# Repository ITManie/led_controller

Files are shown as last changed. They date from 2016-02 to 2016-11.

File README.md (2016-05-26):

# led-controller





Arduino project to control RGB LED strip

## Part list
 - IQRF Development set [IQRF DS-START-04](http://eshop.iqrf.org/products/detail/DS-START-04)
 - IQRF Breakout board [IQRF BB-01](http://eshop.iqrf.org/products/detail/IQRF-BB-01)
 - IQRF gateway (for example [IQRF GW-ETH-02A](http://eshop.iqrf.org/products/detail/GW-ETH-02A%2872D%29))
 - Atmel MCU with Arduino firmware or Adruino (for example [Arduino Nano](http://www.tme.eu/en/details/a000005/arduino-development-kits/arduino/arduino-nano/))
 - 3x [STMicroelectronics TIP122](http://www.tme.eu/en/details/tip122/npn-tht-darlington-transistors/st-microelectronics/)
 - 5V voltage stabiliser (for example [ON Semiconductor MC78M05CTG](http://www.tme.eu/en/details/mc78m05ctg/unregulated-voltage-regulators/on-semiconductor/))
 - RGB LED strip (for example [OptoFlash OPRGB5060-6012B](http://www.tme.eu/en/details/oprgb5060-6012b/light-sources-led-ribbon/optoflash/))
 - 5,5/2,1mm DC jack (for example [CLIFF FC68148](http://www.tme.eu/en/details/fc68148/dc-power-connectors/cliff/))
 - 12V power supply (for example [ESPE ZSIDT12/3A](http://www.tme.eu/en/details/zsidt12_3a/mains-power-supplies/espe/))
 - terminal block PCB mount (for example [Degson Electronics DG300-5.0-02P-12-00A(H)](http://www.tme.eu/en/details/dg300-5.0-2p12/terminal-blocks-pcb-mount/degson-electronics/dg300-50-02p-12-00ah/))

## Arduino libraries

 * [IQRF](https://github.com/iqrfsdk/clibiqrf-arduino)
 * [MsTimer2](https://github.com/PaulStoffregen/MsTimer2)

## Packets

### Ping
<table>
<tr>
<th>0-FF</th>
<th>100-1FF</th>
<th>200-2FF</th>
<th>300-3FF</th>
<th>400-4FF</th>
<th>500-5FF</th>
</tr>
<tr>
<td>version</td>
<td>type</td>
<td colspan="4">address</td>
</tr>
<tr>
<td>0</td>
<td>0</td>
<td>0-FF</td>
<td>0-FF</td>
<td>0-FF</td>
<td>0-FF</td>
</tr>
</table>

### Pong
<table>
<tr>
<th>0-FF</th>
<th>100-1FF</th>
<th>200-2FF</th>
<th>300-3FF</th>
<th>400-4FF</th>
<th>500-5FF</th>
</tr>
<tr>
<td>version</td>
<td>type</td>
<td colspan="4">address</td>
</tr>
<tr>
<td>0</td>
<td>1</td>
<td>0-FF</td>
<td>0-FF</td>
<td>0-FF</td>
<td>0-FF</td>
</tr>
</table>

### Set color
<table>
<tr>
<th>00-FF</th>
<th>100-1FF</th>
<th>200-2FF</th>
<th>300-3FF</th>
<th>400-4FF</th>
<th>500-5FF</th>
<th>600-6FF</th>
<th>700-7FF</th>
<th>800-8FF</th>
<th>900-9FF</th>
</tr>
<tr>
<td>version</td>
<td>type</td>
<td colspan="4">address</td>
<td>red</td>
<td>green</td>
<td>blue</td>
<td>alpha</td>
</tr>
<tr>
<td>0</td>
<td>2</td>
<td>0-FF</td>
<td>0-FF</td>
<td>0-FF</td>
<td>0-FF</td>
<td>0-FF</td>
<td>0-FF</td>
<td>0-FF</td>
<td>0-1</td>
</tr>
</table>

## Schema
### Prototype
Schema
### Production
Schema

## License
led-controller is licensed under the GPLv3 license:

 > Copyright (C) 2016 Roman Ondráček
 > 
 > This program is free software: you can redistribute it and/or modify
 > it under the terms of the GNU General Public License as published by
 > the Free Software Foundation, either version 3 of the License, or
 > (at your option) any later version.
 > 
 > This program is distributed in the hope that it will be useful,
 > but WITHOUT ANY WARRANTY; without even the implied warranty of
 > MERCHANTABILITY or FITNESS FOR A PARTICULAR PURPOSE.  See the
 > GNU General Public License for more details.
 > 
 > You should have received a copy of the GNU General Public License
 > along with this program.  If not, see <http://www.gnu.org/licenses/>.

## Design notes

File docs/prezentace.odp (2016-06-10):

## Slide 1

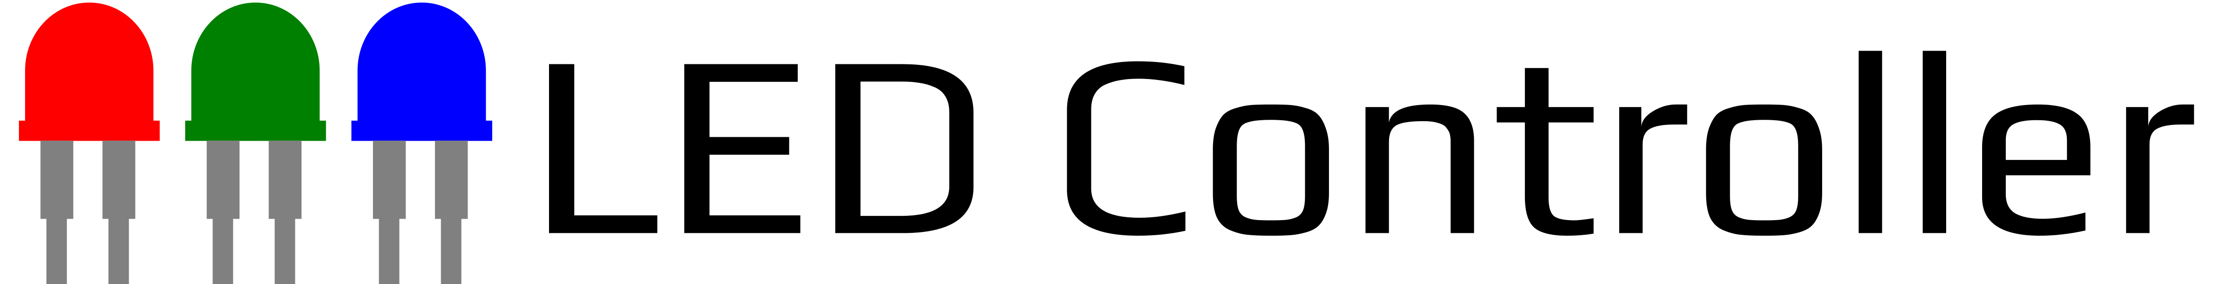
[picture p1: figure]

## Seznámení s projektem

LED Controller je open source (https://gitlab.com/Roman3349/led-controller) projekt, který ovládá RGB LED pásek. Používá IQRF bezdrátové moduly, IQRF Cloud, IQRF Ethernet bránu a Atmel 8-bitový AVR mikrokontrolér s Arduino firmwarem.

## Zdrojové kódy

- Projekt: https://gitlab.com/Roman3349/led-controller
- Rozšížení pro Nette: https://gitlab.com/Roman3349/iqrf-cloud-nette

## Komunikace

Komunikace modulu s IQRF Cloudem je zajištěna pomocí IQRF Ethernet brány.

Komunikace IQRF Cloudu s webovou aplikací je zajištěna pomocí mého rozšíření (https://gitlab.com/Roman3349/iqrf-cloud-nette) pro Nette framework.

## Bezdrátový modul

Použil jsem bezdrátový modul IQRF DCTR-72DAT, který vyvíjí česká firma MICRORISC s.r.o.,
která sídlí v Jičíně.

## Bezdrátový modul

Výhody

- Mesh sítě
- Robustnost
- SDK pro mnoho platforem

Nevýhody

- Vysoká cena
- Malá rychlost

## Aplikace

Aplikace pro mikrokontrolér je napsána v jazyce Arduino.

Webová aplikace je napsána v jazyce PHP a používá Nette framework.

## Děkuji za pozornost

Roman Ondráček

ondracek.roman@centrum.cz

gitlab.com/u/Roman3349

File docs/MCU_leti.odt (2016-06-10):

LED Kontrolér

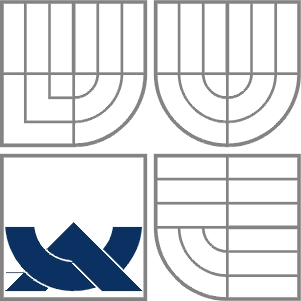
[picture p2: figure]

| VYSOKÉ UČENÍ TECHNICKÉ V BRNĚ BRNO UNIVERSITY OF TECHNOLOGY
| FAKULTA ELEKTROTECHNIKY A KOMUNIKAČNÍCH TECHNOLOGIÍ ústav teoretické a experimentální elektrotechniky FACULTY OF ELECTRICAL ENGINEERING AND COMMUNICATION DEPARTMENT OF theoretical and experimental electrical engineering

SOUTĚŽNÍ PŘÍSPĚVEK V RÁMCI ZÁVĚREČNÉHO WORKSHOPU
MIKROKONTROLÉRY LETÍ 2016

AUTOR PRÁCE ROMAN ONDRÁČEK

BOSKOVICE 2016

# Obsah

Roman Ondráček, Gymnázium Boskovice, roman.ondracek.2014@gymbos.net

# Úvod

Na trhu jsou nabízeny levné RGB LED kontroléry, které bohužel nenabízejí možnost pohodlně je ovládat z daného chytrého mobilního telefonu, tabletu či počítače, protože pro své ovládání používají infračervené záření. Tento způsob je velice levný, nespolehlivý a nedají se pomocí něj ovládat dva shodné RGB LED kontroléry, protože dálkový ovladač vždy vysílá při stisknutí tlačítka infračervené záření o stejné frekvenci. Z tohoto důvodu nelze nezávisle ovládat dva LED pásky, které jsou blízko u sebe. Cílem této práce je navrhnout a vyrobit zařízení, které bude řešit jmenované problémy.

# LED kontrolér

LED kontrolér je zařízení ovládající LED pásek, který může být jednobarevný nebo může být složen z RGB LED, pomocí nichž se dá vytvořit světlo s různými barvami. Dělit se může také na LED kontroléry, na DIN lištu elektrického rozvaděče nebo na LED kontroléry umístěné v obyčejné krabičce. Dále se může lišit podle typu ovládání, například může být ovládán bezdrátovými moduly, tlačítky na krabičce nebo pomocí infračerveného dálkového ovládání. Všechny LED kontroléry spínají LED pásek pomocí tranzistorů nejčastěji MOSFETy nebo dvěma bipolárními tranzistory v tzv. Darlingtonovém zapojením.

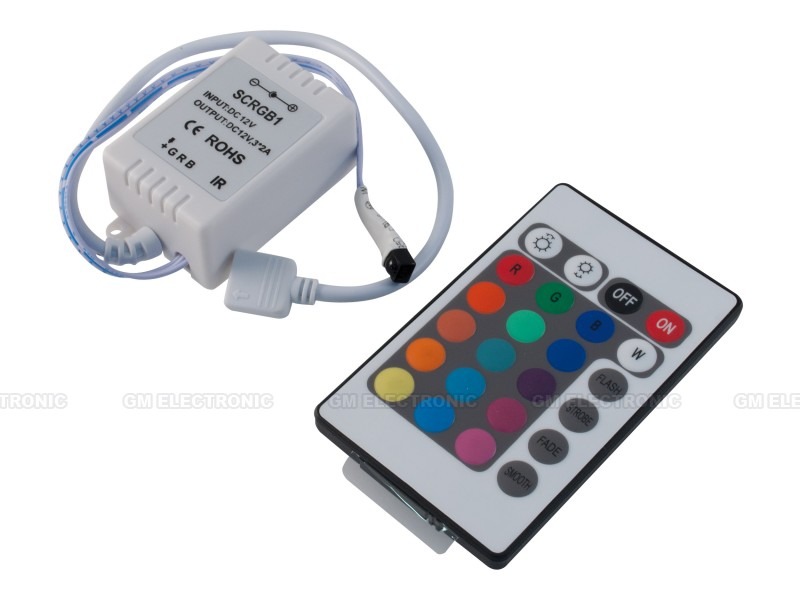
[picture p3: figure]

Ilustrace 1: Ukázka RGB LED kontroléru

# Mikrokontrolér ATmega 328P

Jako řídící mikrokontrolér jsem zvolil Atmel ATmega 328P, který běží na frekvenci 16 MHz. Jedná se o 8‑bitový mikrokontrolér s architekturou AVR, která používá architekturu RISC, jenž má omezenou instruktážní sadu a rychlé vykonávání instrukcí. Flash paměť pro program má velikost 32 kB, paměť EEPROM má velikost 1 kB a paměť SRAM má velikost 2 kB. Má 23 programovatelných vstupních a výstupních pinů. Některé piny jsou určeny pro speciální použití jako je A/D převodník, analogový komparátor, UART, SPI, I2C, PWM, časovač/čítač nebo přerušení (IRQ).

Pro jednoduší vývoj byl zvolen vývojový kit Arduino Nano, který tento mikrokontrolér obsahuje a navíc obsahuje vestavěný převodník ze sériové linky na USB a lze jej zasunout do nepájivého pole.

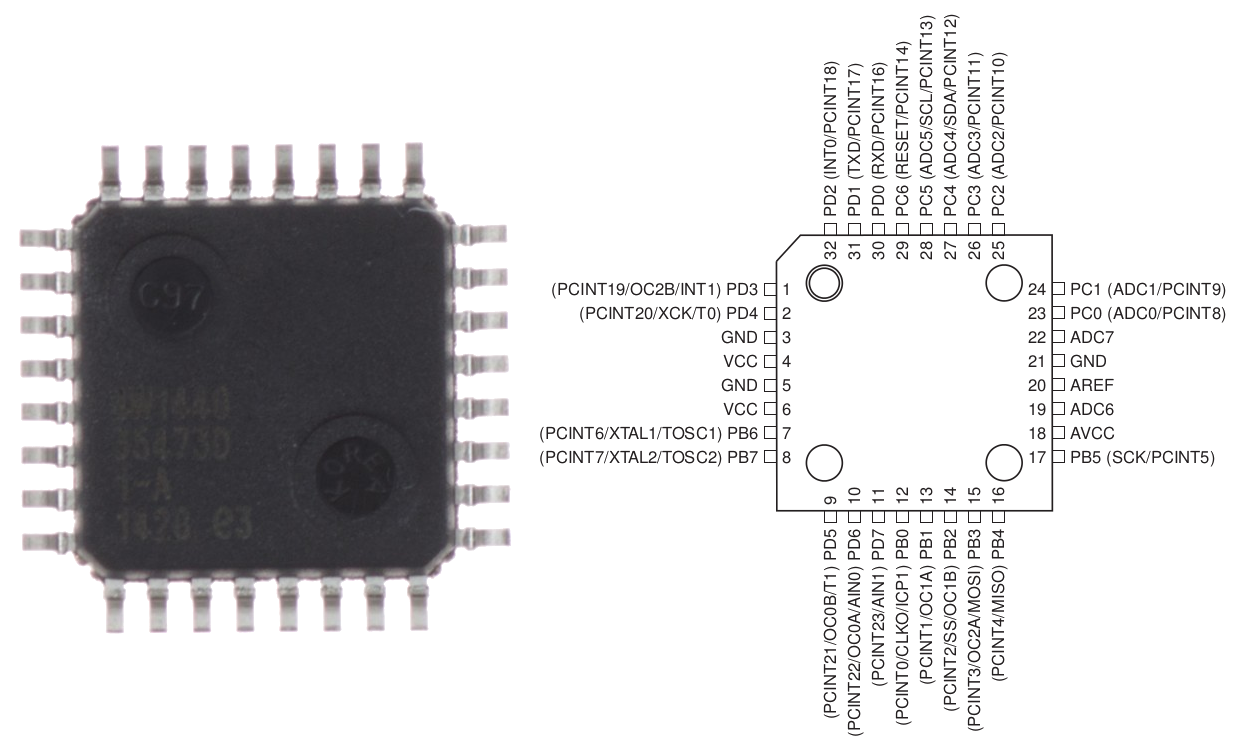
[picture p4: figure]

Ilustrace 2: Pouzdro TQFP32 Atmega328P od firmy Atmel jak vypadá ve skutečnosti a s popisem vývodů

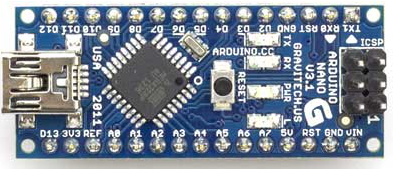
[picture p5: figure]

Ilustrace 3: Arduino Nano

# Bezdrátový modul DCTR-72DA

Bezdrátový modul jsem použil IQRF DCTR-72DA, který vyrábí čeká firma MICRORISC s.r.o., sídlící v Jičíně. Modul může vysílat na bezlicenčních pásmech 916 MHz, které je určené pro Ameriku, a 868 MHz, určené pro zbytek světa. Vysílací výkon modulu je 12,5 mW. Modul má integrovanou anténu na svém plošném spoji. Plošný spoj modulu má podobné rozměry (až na výšku je má shodné) jako SIM karta, proto je použit slot na SIM karty pro jeho připojení k mikrokontroléru. Pro komunikaci používá tzv. mesh neboli smíšenou topologii, která má výhody v redundantnosti a v neexistenci centrálního prvku a nevýhody v nutné ochraně proti zacyklení a v nutnosti směrování provozu.

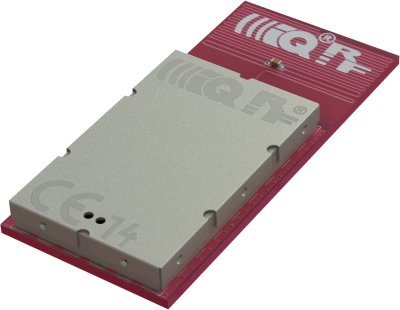
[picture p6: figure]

Ilustrace 4: Modul IQRF DCTR-72DA

K mikrokontroléru se připojuje pomocí sběrnice SPI (Serial Peripheral Interface), pro komunikaci je nutné mít do programu pro mikrokontrolér vloženou knihovnu. Ta je určena pouze pro vývojové kity, které používají platformu Arduino, tedy Arduino a ChipKIT uC32, který vyrábí firma Microchip; místo tradičního mikroprocesoru pro Arduino od firmy Atmel je zde použit mikrokontrolér PIC32 od firmy Microchip. Protože je použit pro připojení slot na SIM karty, musel jsem použít adaptér IQRF-BB-01[^1], který obsahuje napěťový regulátor z 5 V na 3,3 V a převodník úrovní, aby se při komunikace s mikrokontrolérem s 5 V logikou nepoškodil modul.

Program pro modul je nutné vyvíjet ve speciálním vývojovém prostředím IQRF IDE a pro nahrání programu je nutný speciální programátor CK‑USB‑04A[^2].

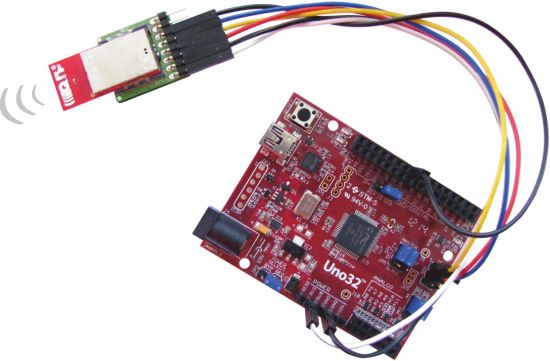
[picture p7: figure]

Ilustrace 5: Ukázkové použití adaptéru IQRF-BB-01

Pro komunikaci s modulem prostřednictvím Internetu je potřeba brána, která může být připojená pomocí Ethernetu, Wi-Fi nebo GSM sítě. Já jsem si vybral bránu GW‑ETH‑02A[^3], která je do Internetu připojená pomocí Ethernetu. Brána poté posílá data do IQRF Cloudu a také odtud je i přijímá. S webovou aplikací komunikuje prostřednictvím API. Pro lepší práci s API ve webové aplikaci, která je objektově napsaná ve skriptovacím jazyku PHP a ve frameworku Nette, jsem vytvořil knihovnu iqrf-cloud-nette, kterou naleznete na mém GitHubu[^4].

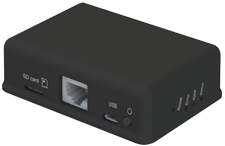
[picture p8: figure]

Ilustrace 6: Brána GW-ETH-02A

# Vývojové prostředí

Pro vybraný bezdrátový modul je pouze k dispozici zdarma stažitelné vývojové prostředí IQRF IDE, které je bohužel pouze pro operační systém Microsoft Windows. Uživatelé Apple OS X nebo libovolné linuxové distribuce nemohou vyvíjet software pro tyto bezdrátové moduly.

Pro vybraný mikrokontrolér existuje mnoho vývojových prostředí. Vybral jsem si Arduino IDE, protože umím pouze základy programovacího jazyka C a Arduino IDE používá zjednodušenou verzi tohoto programovacího jazyka. Arduino IDE je multiplatformní a je open‑source.

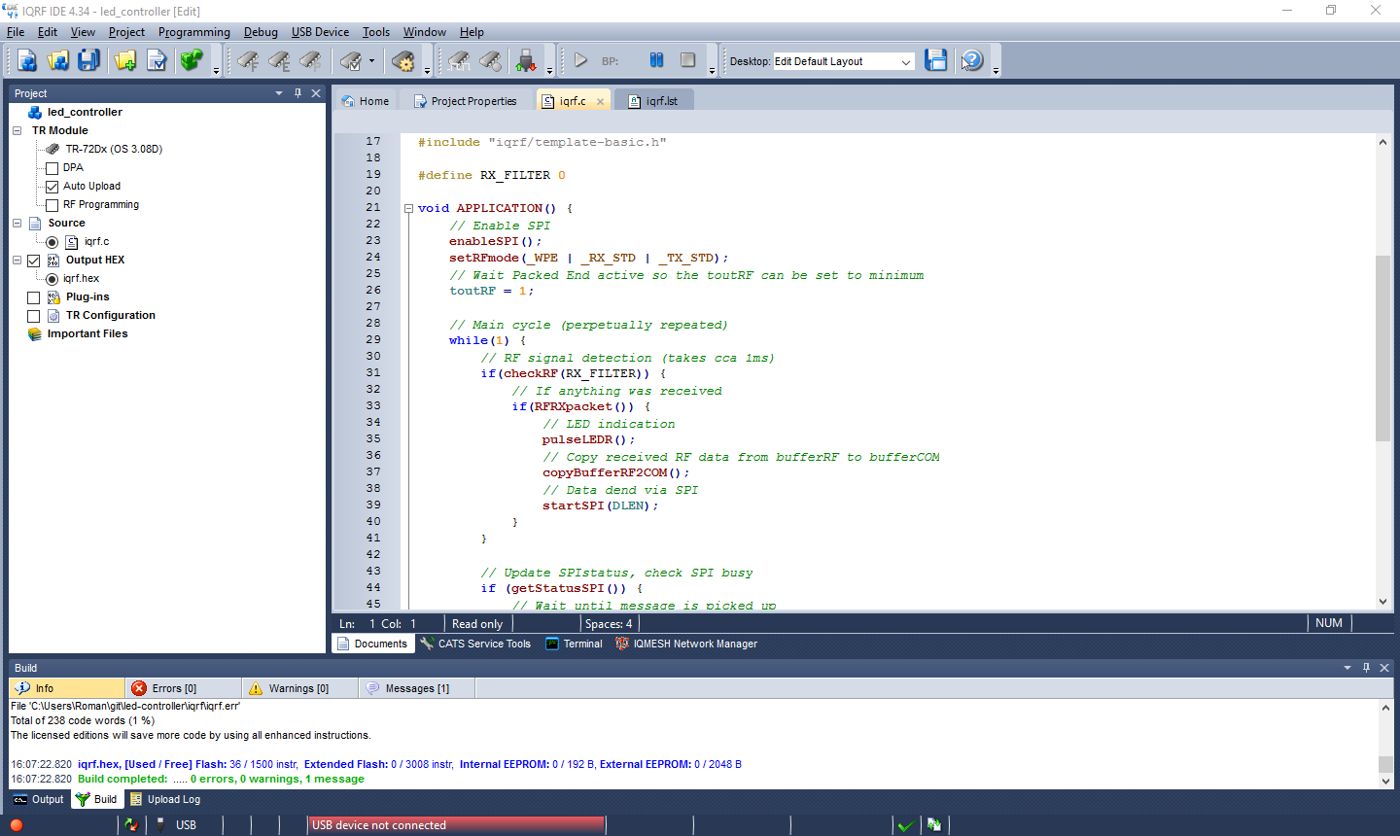
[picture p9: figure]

Ilustrace 7: Vývojové prostředí IQRF IDE

Pro vývoj webové aplikace a knihovny pro IQRF Cloud API jsem zvolil vývojové prostředí Oracle NetBeans , které je multiplatformní a je open‑source. Toto vývojové prostředí je určeno pro jazyky C, C++, Java, PHP, HTML5 a JavaScript.

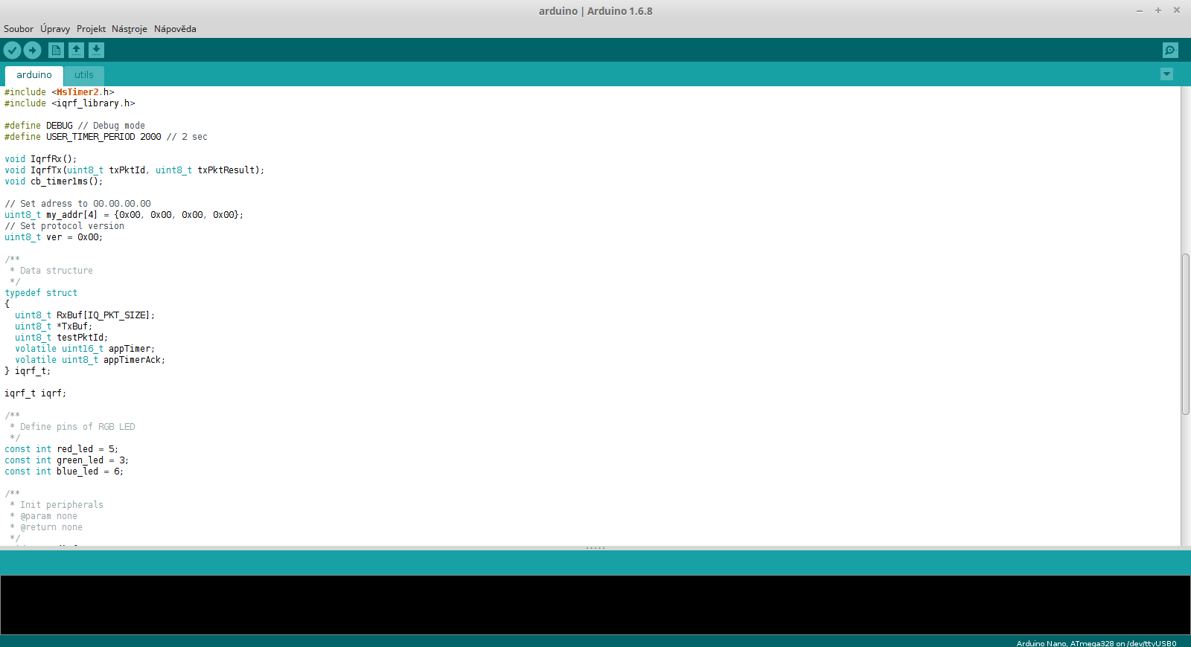
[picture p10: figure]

Ilustrace 8: Vývojové prostředí Arduino IDE

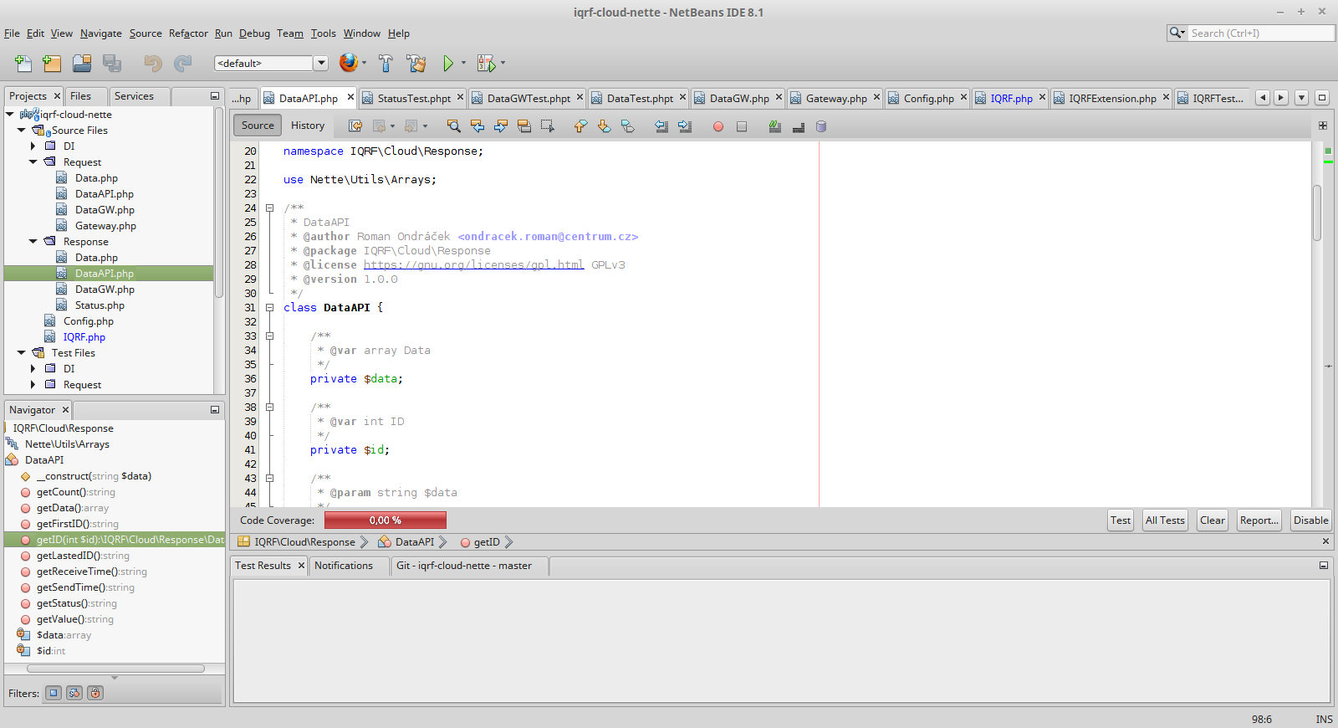
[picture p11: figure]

Ilustrace 9: Vývojové prostředí Oracle NetBeans IDE

# Návrh zapojení

## Hardware

Pro svou funkčnost potřebuje výrobek 12 V napájecí zdroj, který je efektivní, malý a bezpečný. Dále 5 V napěťový regulátor pro napájení Arduina a bezdrátového modulu, IQRF bezdrátový modul a adaptér pro něj, 3 NPN tranzistory v Darlingtonovém zapojení TIP120 (nebo TIP121, TIP122) (s předřazenými 1 kΩ odpory) pro spínání RGB LED pásku a RGB LED pásek, který budeme pomocí tohoto zařízení ovládat. Dále jsou potřeba kondenzátory (jeden elektrolytický, 3 keramické blokovací kondenzátory a 2 keramické kondenzátory za krystal) a 16 MHz krystal.

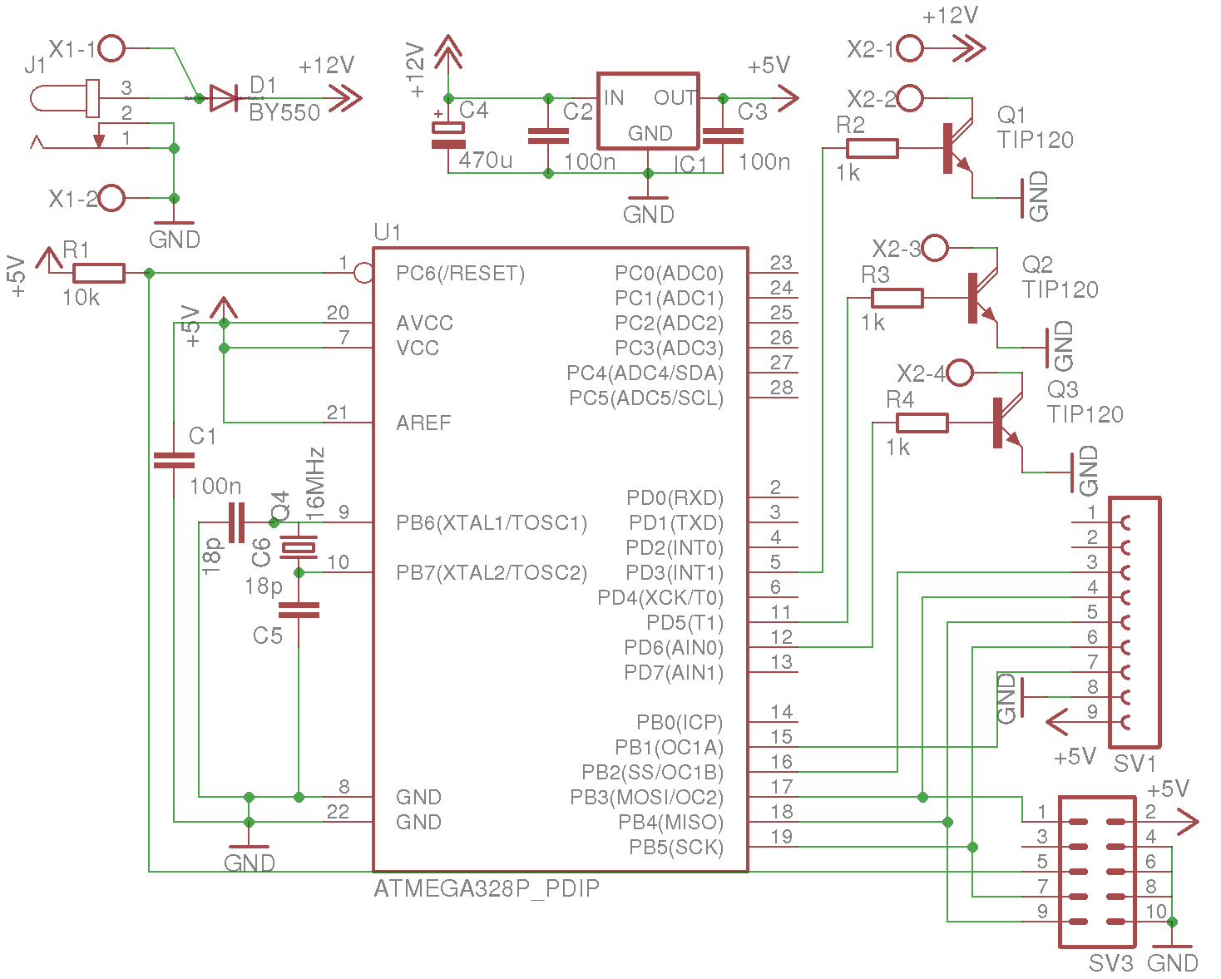
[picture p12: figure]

Ilustrace 10: Schéma zapojení

Prototyp byl sestaven na nepájivém poli a byl zde použit vývojový kit Arduino Nano. Pro finální produkt byla navrhnuta deska plošných spojů a byl zde použit již samotný mikrokontrolér Atmel ATmega328P v pouzdře DIP-28, protože bude deska plošných spojů vložena do třímodulové krabičky na DIN lištu elektrického rozvaděče.

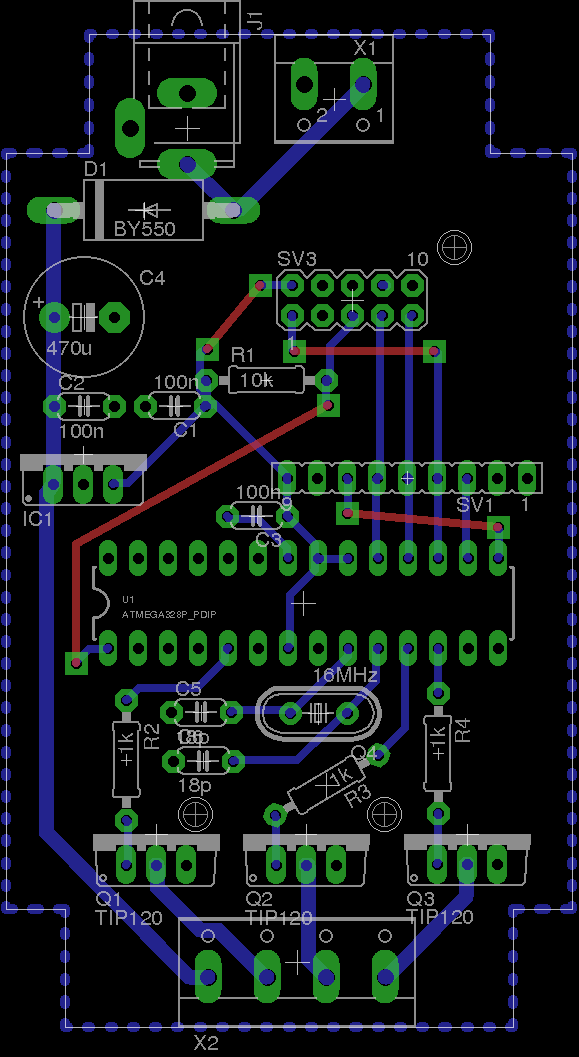
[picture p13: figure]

Ilustrace 11: Návrh desky plošných spojů

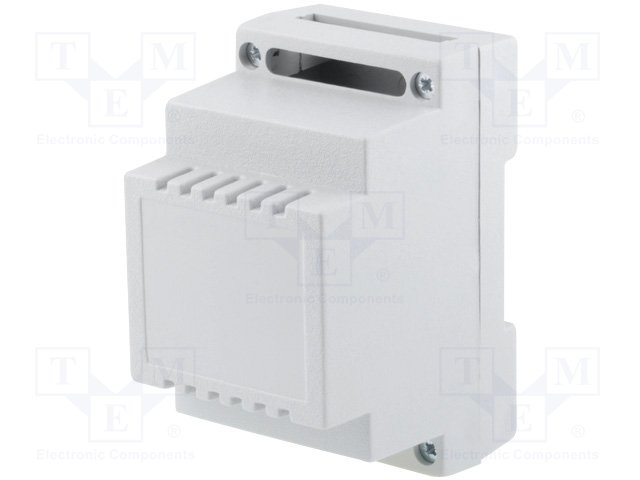
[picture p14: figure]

Ilustrace 12: Použitá třímodulová krabička na DIN lištu

## Software

Pro program pro mikrokontrolér byl použit jazyk Arduino, protože je na naučení jednoduší než programovací jazyk C nebo C++. Program pro bezdrátový modul byl napsán v programovacím jazyce C. Webová aplikace byla napsána v skriptovacím jazyce PHP a byl použit český framework Nette. Pro verzování programu byl použit Git.

Komunikace mezi webovou aplikací a modulem obstarává brána a IQRF Cloud, se kterým webová aplikace komunikuje pomocí API. Data jsou odesílána v paketu, který obsahuje verzi protokolu, typ paketu, adresu a další data. Adresa je 32‑bitová.

### Pakety

#### Ping

Tento paket odesílá webová aplikace, aby zjistila zda je LED kontrolér s danou adresou připojen do sítě.

#### Pong

Tento paket odesílá LED kontrolér jako odpověď na paket ping.

#### Set color

Tento paket odesílá webová aplikace, aby nastavila barvu RGB LED pásku na daném LED kontroléru.

# Závěr

Výsledkem této práce je funkční produkt sloužící k ovládání RGB LED pásku pomocí webové aplikace.

# Literatura

- IR RGB LED kontrolér OS-OC013AIG2, In: GME [online]. [cit. 2016-04-28]. Dostupné z: http://www.gme.cz/ir-rgb-led-kontroler-os-oc013aig2-p759-996
- Atmel ATmega328P datasheet. In: Atmel [online]. [cit. 2016-04-28]. Dostupné z: http://www.atmel.com/images/Atmel-8271-8-bit-AVR-Microcontroller-ATmega48A-48PA-88A-88PA-168A-168PA-328-328P_datasheet_Complete.pdf
- IQRF TR-72D datasheet. In: IQRF [online]. [cit. 2016-04-28]. Dostupné z: http://www.iqrf.org/weben/downloads.php?id=337
- COMBIPLAST CP-Z-102-ABS. In: TME [online]. [cit. 2016-04-28]. Dostupné z: http://www.tme.eu/cz/details/cp-z-102-abs/krabicky-na-listu-din/combiplast/

[^1] http://iqrf.org/products/development-tools/development-kits/iqrf-bb-01
[^2] http://iqrf.org/products/development-tools/development-kits/ck-usb-04a
[^3] http://iqrf.org/products/gateways/gw-eth-02a
[^4] https://github.com/Roman3349/iqrf-cloud-nette

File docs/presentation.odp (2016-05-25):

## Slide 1


## What is LED Controller

LED Controller is open source project (https://gitlab.com/Roman3349/led-controller) that controls RGB LED strips using IQRF wireless modules, IQRF Cloud with IQRF Ethernet gateway and Atmel 8-bit AVR microcontroller with Arduino firmware.

## Communication

Communication with IQRF Cloud is provided via IQRF Ethernet gateway.

Communication with web application is provided
via my Nette extension (https://gitlab.com/Roman3349/iqrf-cloud-nette).

## Applications

Application for microcontroller is written in Arduino language.

Web application is written in PHP using the Nette framework.

## Photos

Prototype

Final product

## Source codes

- Project: https://gitlab.com/Roman3349/led-controller
- Nette extension: https://gitlab.com/Roman3349/iqrf-cloud-nette

## Thank you

Roman Ondráček

ondracek.roman@centrum.cz

gitlab.com/u/Roman3349

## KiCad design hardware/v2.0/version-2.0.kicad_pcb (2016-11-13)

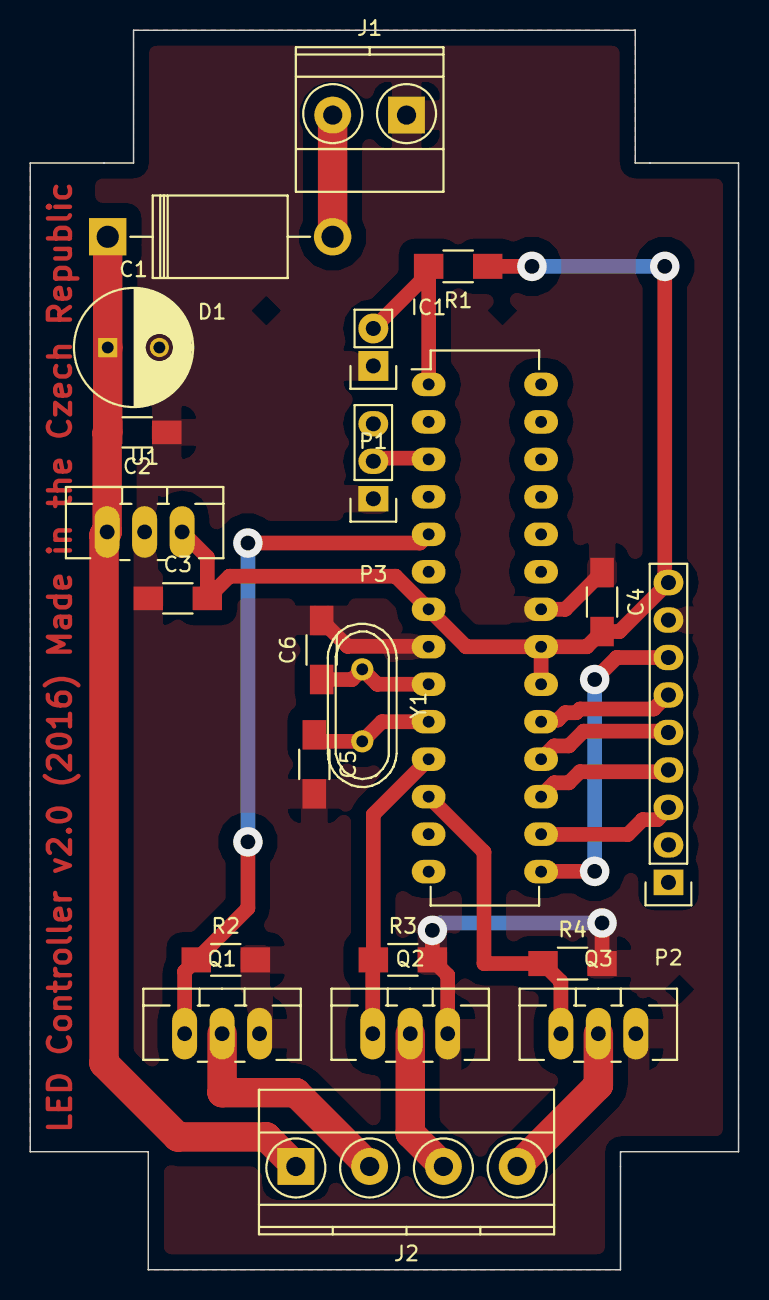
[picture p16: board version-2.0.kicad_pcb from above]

Board: 2 copper layers, 48.0 x 84.0 mm, 22 parts (0 on the bottom side), 20 nets.

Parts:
C1: 470u; C_Radial_D8_L11.5_P3.5
C2, C3, C4: 100n; C_1206_HandSoldering
C5, C6: 18p; C_1206_HandSoldering
D1: BY550-400; Diode_DO-201AD_Horizontal_RM15
IC1: ATMEGA328P-P; DIP-28_W7.62mm_LongPads
J1: DG300-5.0; TerminalBlock_Pheonix_MKDS1.5-2pol
J2: RGB LED; TerminalBlock_Pheonix_MKDS1.5-4pol
P1: CONN_01X02; Pin_Header_Straight_1x02
P2: IQRF BB-01; Pin_Header_Straight_1x09
P3: UART; Pin_Header_Straight_1x03
Q1, Q2, Q3: IRLB8721PBF; TO-220_Neutral123_Vertical_LargePads
R1, R2, R3, R4: 10k; R_1206_HandSoldering
U1: MC78M05CTG; TO-220_Neutral123_Vertical_LargePads
Y1: CRYSTAL; Crystal_HC49-U_Vertical

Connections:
+5V: C3.2, C4.2, IC1.7, IC1.20, IC1.21, P2.9, R1.1, U1.3
+12V: C1.1, C2.2, D1.1, J2.1, U1.1
/MISO: IC1.18, P2.5
/MOSI: IC1.17, P2.4
/RX: IC1.2, P3.3
/SCK: IC1.19, P2.6
/SS: IC1.16, P2.3
/TR_RESET: IC1.15, P2.7
/TX: IC1.3, P3.2
GND: C1.2, C2.1, C3.1, C4.1, C5.2, C6.2, IC1.8, IC1.22, J1.1, P1.1, P2.8, P3.1, Q1.3, Q2.3, Q3.3, R2.2, R3.2, R4.2, U1.2
unnamed: C5.1, IC1.10, Y1.2
unnamed: C6.1, IC1.9, Y1.1
unnamed: D1.2, J1.2
unnamed: IC1.1, P1.2, R1.2
unnamed: IC1.5, Q1.1, R2.1
unnamed: IC1.11, Q2.1, R3.1
unnamed: IC1.12, Q3.1, R4.1
unnamed: J2.2, Q1.2
unnamed: J2.3, Q2.2
unnamed: J2.4, Q3.2

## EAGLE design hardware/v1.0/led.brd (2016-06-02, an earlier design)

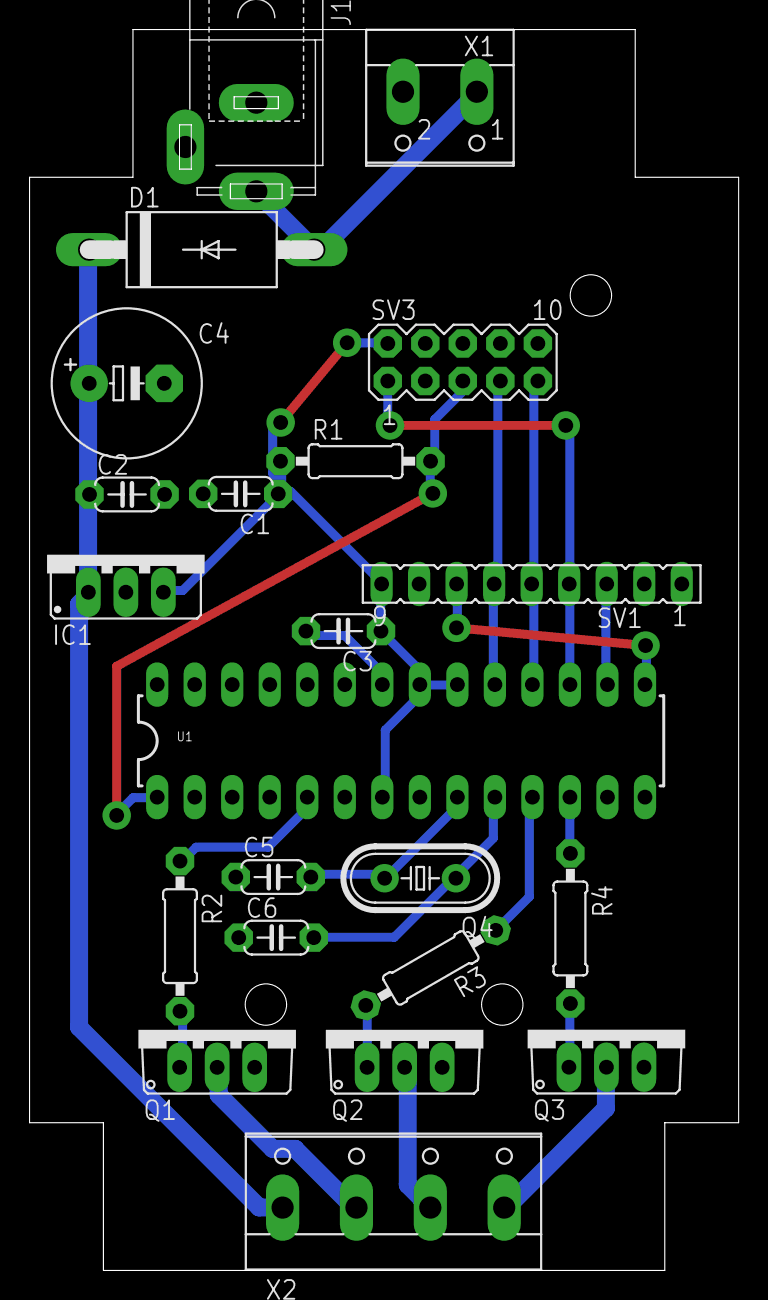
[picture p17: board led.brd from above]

Board: 2 copper layers, 48.0 x 84.0 mm, 22 parts (0 on the bottom side), 21 nets.

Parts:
C1, C2, C3: 100n; C050-024X044
C4: 470u; E5-10,5
C5, C6: 18p; C050-024X044
D1: BY550; DO27-15
IC1: 78XXS
J1: SPC4078
Q1, Q2, Q3: TIP120; TO220AV
Q4: 16MHz; HC49/S
R1: 10k; 0207/10
R2, R3, R4: 1k; 0207/10
SV1: FE09
SV3: MA05-2
U1: ATMEGA328P_PDIP; DIL28-3
X1: W237-102
X2: W237-4

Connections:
+5V: C1.1, C3.1, IC1.OUT, R1.1, SV1.9, SV3.2, U1.7, U1.20, U1.21
+12V: C2.1, C4.+, D1.C, IC1.IN, X2.1
GND: C1.2, C2.2, C3.2, C4.-, C5.1, C6.1, IC1.GND, J1.1, J1.2, Q1.E, Q2.E, Q3.E, SV1.8, SV3.4, SV3.6, SV3.8, SV3.10, U1.8, U1.22, X1.2
unnamed: Q3.C, X2.4
unnamed: SV1.5, SV3.9, U1.18
unnamed: D1.A, J1.3, X1.1
unnamed: Q1.B, R2.2
unnamed: R1.2, SV3.5, U1.1
unnamed: SV1.4, SV3.1, U1.17
unnamed: SV1.3, U1.16
unnamed: SV1.7, U1.15
unnamed: Q2.C, X2.3
unnamed: Q1.C, X2.2
unnamed: R4.1, U1.12
unnamed: R3.1, U1.11
unnamed: R2.1, U1.5
unnamed: SV1.6, SV3.7, U1.19
unnamed: Q2.B, R3.2
unnamed: Q3.B, R4.2
S$1: C6.2, Q4.1, U1.10
S$2: C5.2, Q4.2, U1.9

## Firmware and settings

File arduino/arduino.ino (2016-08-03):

/**
 * Copyright (C) 2016 Roman Ondráček
 *
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
 * You should have received a copy of the GNU General Public License
 * along with this program.  If not, see <http://www.gnu.org/licenses/>.
 */

/*
                      _____
           __________| USB |__________
          |          |_____|          |
 IQRF_SCK | [*]D13             D12[*] | IQRF_MISO
          | [ ]3.3V            D11[*]~| IQRF_MOSI
          | [ ]V.ref   ___     D10[*]~| IQRF_SS
          | [ ]A0     | N |     D9[*]~| IQRF_TRPWR
          | [ ]A1     | A |     D8[ ] |
          | [ ]A2     | N |     D7[ ] |
          | [ ]A3     |_0_|     D6[*]~| LED_BLUE
          | [ ]A4               D5[*]~| LED_RED
          | [ ]A5               D4[ ] |
          | [ ]A6               D3[*]~| LED_GREEN
          | [ ]A7               D2[ ] |
 IQRF_+5V | [*]5V              GND[*] | LED_GND
          | [ ]RST             RST[ ] |
 IQRF_GND | [*]GND 5V MOSI GND TX1[ ] |
          | [ ]Vin [ ] [ ] [ ] RX1[ ] |
          |        [ ] [ ] [ ]        |
          |       MISO SCK RST        |
          | NANO-V3                   |
          |___________________________|
 */
#include <Arduino.h>
#include <MsTimer2.h>
#include <IQRF.h>

#define DEBUG // Debug mode
#define USER_TIMER_PERIOD 2000 // 2 sec

void msTimerCallback();
boolean isMyAddress(uint8_t buf[]);
void receivePing();
void sendPong(uint8_t addr[], uint8_t buf[]);
void setColor(uint8_t buf[]);
void setColorRGB(uint8_t red, uint8_t green, uint8_t blue, uint8_t alpha);
void rxHandler();
void txHandler(uint8_t packetId, uint8_t packetResult);

// Set adress to 00.00.00.00
uint8_t my_addr[4] = {0x00, 0x00, 0x00, 0x00};
// Set protocol version
uint8_t ver = 0x00;

// Instances
IQRF iqrf;
IQRFTR iqrfTr;

/**
 * App data structure
 */
typedef struct {
  uint8_t rxBuffer[PACKET_SIZE]; //!< Rx buffer
  uint8_t *txBuffer; //!< Tx buffer
  uint8_t packetId; //!< Packet ID
  volatile uint16_t timer; //!< Timer
  volatile bool timerAck; //!< Timer action
} appVars_t;
appVars_t appVars;

/*
 * Define pins of RGB LED
 */
const int red_led = 5;
const int green_led = 3;
const int blue_led = 6;

/**
 * Init peripherals
 */
void setup() {
  pinMode(red_led, OUTPUT);
  pinMode(green_led, OUTPUT);
  pinMode(blue_led, OUTPUT);
  Serial.begin(9600);
  iqrf.begin(rxHandler, txHandler);
  switch(iqrfTr.getModuleType()) {
    case iqrfTr.types::TR_52D:
      Serial.println("IQRF module: TR-52D");
      break;
    case iqrfTr.types::TR_72D:
      Serial.println("IQRF module: TR-72D");
      break;
    default:
      Serial.println("IQRF module: UNKNOWN");
      break;
  }
  MsTimer2::set(1, msTimerCallback);
  MsTimer2::start();
  memset(&appVars, 0, sizeof(appVars_t));
  appVars.timer = USER_TIMER_PERIOD;
  Serial.println("Init done.");
}

/**
 * Main loop
 */
void loop() {
  // TR module SPI comunication driver
  iqrf.driver();
}

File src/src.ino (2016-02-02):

#include <SPI.h>
#include <MsTimer2.h>
#include <iqrf_library.h>

#define USER_TIMER_PERIOD 5000 // 5 sec


/**
 * Local prototypes
 */
void MyIqrfRxHandler();
void MyIqrfTxHandler(UINT8 txPktId, UINT8 txPktResult);
void AppTimerHandler();
void cb_timer1ms();


/**
 * Global variables
 */

//App data
typedef struct 
{
  uint8_t myIqrfRxBuf[IQ_PKT_SIZE];
  uint8_t *myIqrfTxBuf;
  uint8_t testPktId;
  volatile uint16_t appTimer;
  volatile uint8_t appTimerAck;
} app_vars_t;

app_vars_t app_vars;

/**
 * Init peripherals
 */

void setup() {
  pinMode(13, OUTPUT);
  Serial.begin(9600);
  IQRF_Init(MyIqrfRxHandler, MyIqrfTxHandler);
  MsTimer2::set(1, cb_timer1ms);
  MsTimer2::start();
  memset(&app_vars, 0, sizeof(app_vars_t));
  app_vars.appTimer = USER_TIMER_PERIOD;
  Serial.println("Init done.");
}

/**
 * Main
 */

void loop() {
  IQRF_Driver();
}

void cb_timer1ms(void) {
  if (app_vars.appTimer) {              
    if ((--app_vars.appTimer) == 0) {
      AppTimerHandler();
      app_vars.appTimer = USER_TIMER_PERIOD;
    }
  }
}

void AppTimerHandler(void) {
  app_vars.appTimerAck = TRUE;
}


void MyIqrfRxHandler(void) {
  IQRF_GetRxData(app_vars.myIqrfRxBuf, IQRF_GetRxDataSize());
  Serial.print("IQRF receive done: ");
  Serial.write(app_vars.myIqrfRxBuf, IQRF_GetRxDataSize());
  Serial.println();
}

void MyIqrfTxHandler(UINT8 txPktId, UINT8 txPktResult) {
  Serial.println("IQRF send done");
}

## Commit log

2016-01-31 Added Arduino project source code
2016-01-31 Fix syntax error in Arduino sources
    [src.ino]
2016-01-31 Fix other syntax error in Arduino project
    [src.ino]
2016-02-02 Replace IQRF library files to platformio installation
    [src.ino]
2016-02-02 Rename src to arduino, rename repository
2016-02-02 Added tested boards
2016-02-02 Remove problematic boards
2016-02-03 Added schematic and RGB LED pins
2016-02-03 Added shitty implementation of reading numbers from buffer for PWM regulation RGB LEDs
2016-02-04 Added skeleton for app powered by Apache Cordova
2016-02-21 Added comments to Arduino code
2016-02-21 Edit schematics in Arduino code
2016-02-23 Set LED pins as outputs
2016-03-14 [eagle] Added schematic and PCB design
    [led_controller.brd, led_controller.sch]
2016-03-15 [Eagle] Create new board
    [led_controller.brd, led_controller.sch]
2016-03-15 [Eagle] Update board
    [led_controller.brd]
2016-03-16 [Eagle] Added schematic and board in pictures
    [led_controller.brd]
2016-03-24 [Arduino] Redefine LED pins
2016-03-26 [Travis CI] Remove unnecessary boards
2016-03-28 [Wercker CI] Remove unnecessary boards
2016-03-30 [Arduino] Fix IQRF module detection
    [arduino.ino]
2016-03-31 [Arduino] Added debug infos
2016-04-13 [LICENSE] Added license header to Arduino and IQRF source code
2016-04-16 [Eagle] New schematic
    [led.sch, led_controller.brd, led_controller.sch]
2016-04-16 [Arduino] Added function to set color of RGB LED strip
2016-04-22 [Eagle] Added board
    [led.brd, led.sch]
2016-04-29 [docs] Added some info about selected wireless module
2016-04-30 [Arduino] Fix bracket in condition
    [utils.ino]
2016-05-04 [webapp] Update Nette framework to version 2.4
2016-05-13 [Arduino] Clean code
2016-05-13 [Eagle] Moved prototype schema to own directory
    [led.brd, led.sch]
2016-05-19 [GitLab CI] Added tests for Arduino code
2016-05-22 Added final board and schema
    [led.brd, led.sch]
2016-05-22 [Eagle] Board repaired
    [led.brd]
2016-05-24 [Eagle] Edited schema and board
    [led.brd, led.sch]
2016-05-24 [Eagle] Added capacitors and resistors
    [led.brd, led.sch]
2016-05-25 Used official library for Arduino
2016-05-26 Fixed mirroing of PCB
2016-05-26 Fixed PCB
    [led.brd]
2016-05-30 [Eagle] Fixed board
    [led.brd, led.sch]
2016-06-02 Updated schema and board
    [led.brd, led.sch]
2016-06-05 Added board to print
2016-06-08 [Arduino] Refactored source code
2016-06-10 [Eagle] Added board and edited schema
2016-08-03 Fixed Arduino sources
2016-11-12 Renamed eagle files
    [led.brd, led.sch]
2016-11-13 Add EDA's files for version 2.0
    [led.brd, led.sch, version-2.0.kicad_pcb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]

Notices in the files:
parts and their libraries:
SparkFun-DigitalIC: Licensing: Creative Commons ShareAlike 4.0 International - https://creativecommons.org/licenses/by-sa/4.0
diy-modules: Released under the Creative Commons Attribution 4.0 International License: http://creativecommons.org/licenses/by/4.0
